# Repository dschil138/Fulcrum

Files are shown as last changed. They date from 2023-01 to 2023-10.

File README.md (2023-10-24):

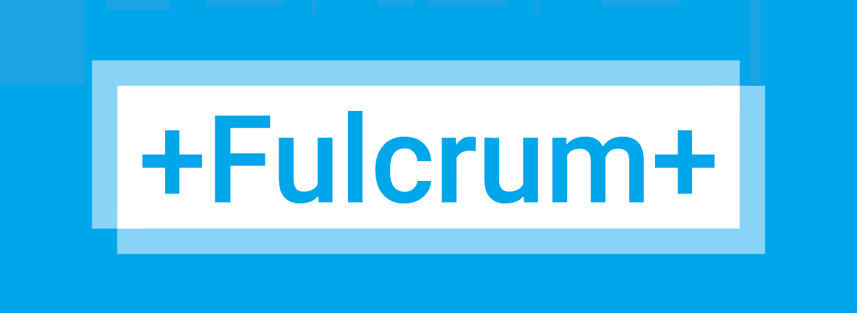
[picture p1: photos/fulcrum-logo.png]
Fulcrum Keyboard Logo


## <h2 align="center"> Leverage the power of opposable thumbs</h2>

<!-- # Fulcrum Keyboard -->

The Fulcrum is a wireless ergonomic keyboard that features 5-way switch joysticks, which are mounted horizontally to take advantage your thumb's natural range of motion.

It runs KMK circuitpython firmware on an nRF52840 microcontroller.

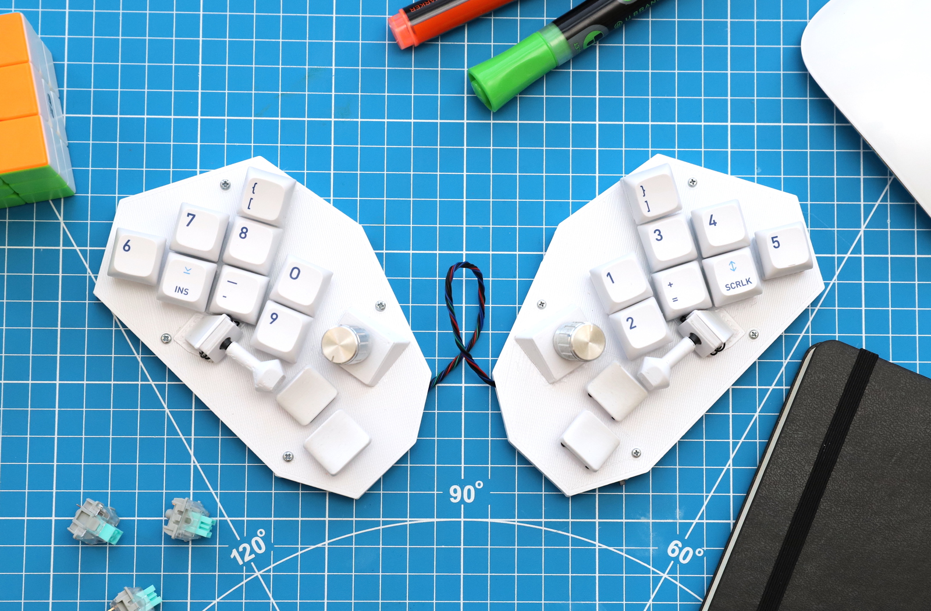
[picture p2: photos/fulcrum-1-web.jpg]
Photo of the Fulcrum Keyboard


There are currently two versions of the Fulcrum: the **20-key version** pictured here, and a **40-key version** pictured below. (These key counts do not include the 5-way switches.)

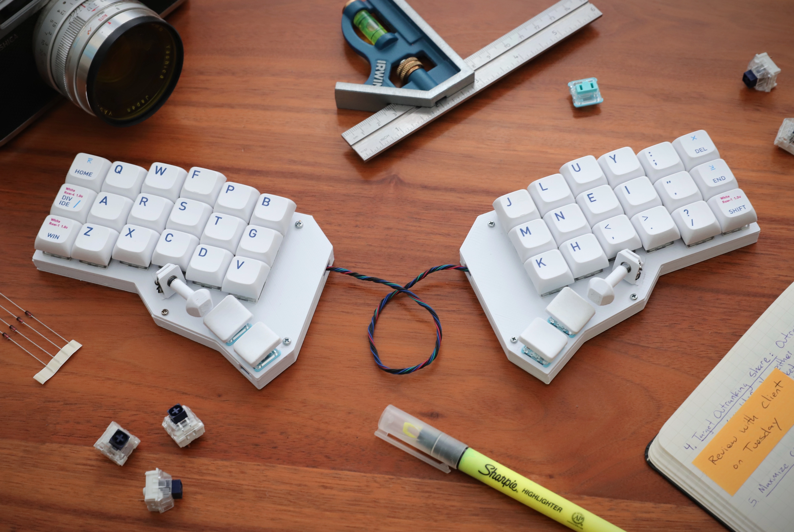
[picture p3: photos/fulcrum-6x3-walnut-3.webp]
40 key version


*(NOTE: there is now a 34-key "beta" version as well)*

## Fulcrum in the Media
- [HackerNews](https://news.ycombinator.com/item?id=34656652)
- [KBD.news (20 key)](https://kbd.news/Fulcrum-1862.html)
- [KBD.news (40 key)](https://kbd.news/40-Fulcrum-1879.html)
- [Hackaday.com](https://hackaday.com/2023/02/04/fulcrum-foils-finger-fatigue/)

# Keyboard Features

## 👍 5-Way Switch Thumb Joysticks

Our thumbs are criminally underutilized on regular keyboards. Your two most capable fingers, both relegated to just one key - the space bar.

Many ergonomic keyboards try to rectify this problem by giving each thumb several keys. This is an improvement, but most people quickly find that it is actually quite difficult for your thumb to stretch over multiple keys and hit something accurately, let alone comfortably. More inefficency!

So what's going on with our phones? Look at how well we use our thumbs to type there. On a smartphone, our thumbs are fast, accurate, and dexterous. Incredibly efficient. What's the disconnect? Why are they so nimble over there, and so lumbering and inaccurate on our keyboards?

> The disconnect is that our thumbs are *opposable*, but for some reason our keyboards keep insisting on giving them the same type of key as our other fingers. Our thumbs want to move in a different direction!

> The 5-way switch joysticks on the Fulcrum are mounted sideways, allowing you to use your thumbs in a dimension that is more similar to how they move when you type on a smartphone. This immediately feels comfortable and natural, because it is how you already use your thumbs most other parts of your daily life.

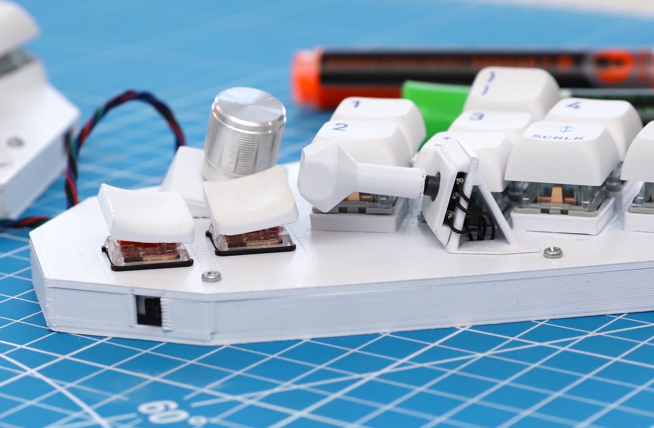
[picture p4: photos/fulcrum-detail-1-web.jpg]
Photo of the Fulcrum Keyboard


With the regular key switch placed below joystick, this actually puts six different actions at the tip of each thumb with very minimal movement.

Most importantly, all of these actions are easily paired with other key presses elsewhere on the keyboard.

> **Note**
> Useful tips to help you choose what functions to assign to the joysticks:
> 1. Pressing "down" (towards the desk) on the joystick should be a layer switch when held. This is because it is the easiest motion to hold & press other keys.
> 2. Mod-Tap works well on them, so consider a "hold" & "tap" key for each
> 3.  The first few times you use them, you may find it hard to not move the whole board around a bit when pressing certain directions. This will go away after a day or two of getting used to the movements.

## Thumb joystick on 20 key Fulcrum  Combos
A combo is when you press two or more keys at the same time to output a different key.

The 20-key version of this keyboard uses a significant number of combos. You don't have to keep them all, but some are important.

Here is a guide to most of the important combos. They are generally split into combos that output words, and combos that output keys or actions (like "delete").

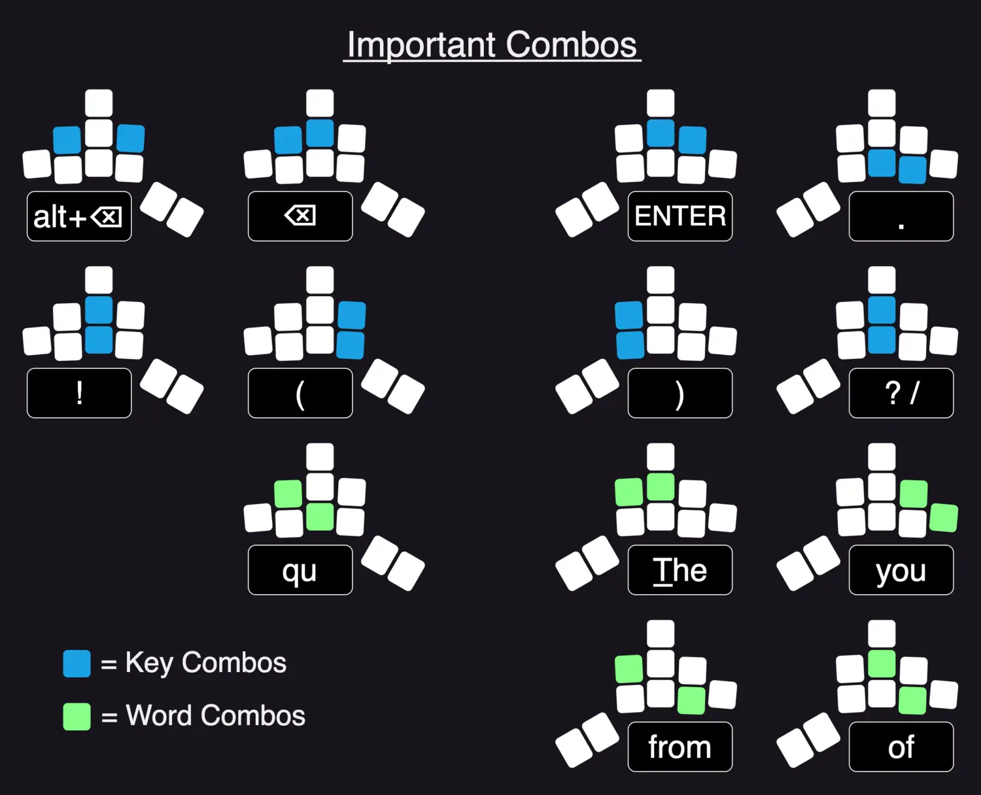
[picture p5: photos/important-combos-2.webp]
Important Combos Diagram


## Thumb joystick on 20 key Fulcrum Word Keys

We type the words "<ins>the</ins>" and "<ins>and</ins>" a lot. Even more-so if you include when they appear as a part of another word (<ins>the</ins>m, <ins>the</ins>y, ano<ins>the</ins>r).

So this keyboard just gives them their own keys!

It's funny, we never question giving Z or Q their own key, but the trigram "the" is more common than either of those letters (2-3 times as common!). Using a single key to type "the" just makes sense.

## 🪜 Optional Key Risers
Most keys have optional risers to help them conform to the shape of your hand. Every key gets them except the thumb keys and the bottom two middle finger keys. The top middle finger key gets a slanted riser.  

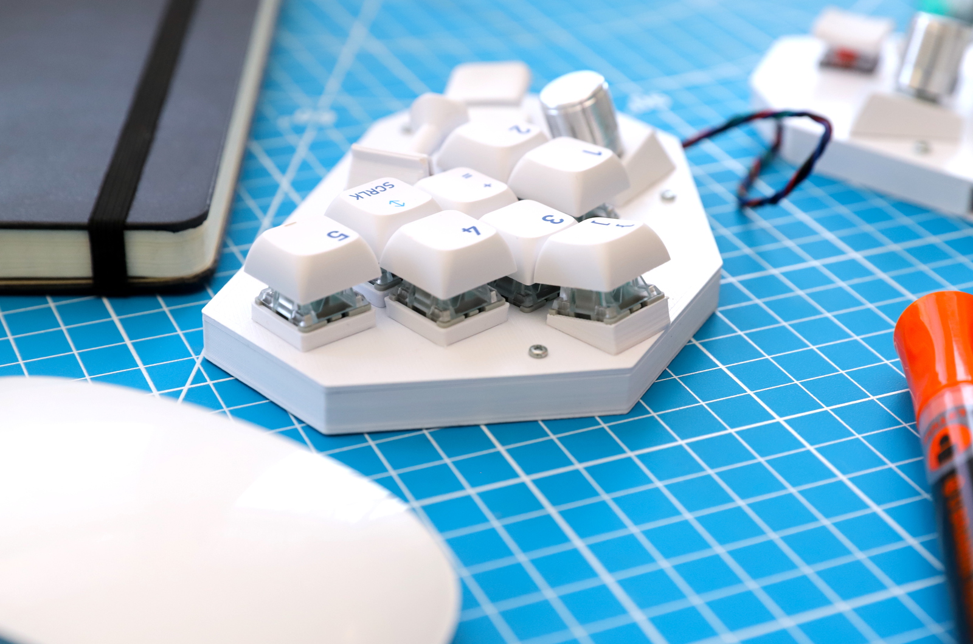
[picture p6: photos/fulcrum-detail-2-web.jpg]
Photo of the Fulcrum Keyboard Detail


To use them, print the top plate of the case as normal, and superglue the risers on top. The switches should friction fit into the risers.

>**Note** 
>The four thumb keys are low profile choc switches, as opposed to the rest which are MX. This is to accommodate the fact that your thumb sits on lower plane than the rest of your fingers, helping to further reduce hand strain.
>
>The custom angled keycaps for the thumb keys can be found in the STLs folder. They are a remix of the great [LPX](https://github.com/levpopov/LPX) design by levpopov.

## Thumb joystick on 20 key Fulcrum  Rotary Encoders

By default, the left rotary encoder scrubs through history (undo/redo) and the right side controls volume. Some other uses include tab switching, scrolling, and tool adjustment in apps like photoshop.

 Similarly to the key risers, the encoders use a slanted riser to tilt the encoders into a more ergonomic position.

# 🛠️ Build Guide

## Thumb joystick on 20 key Fulcrum  Version Files

There are currently two versions of the Fulcrum - the 20-key version you see in most of the photos above, and a 40-key version pictured below.

This repo contains the STLs and firmware files for both versions. The 40-key version is newer - the keymap layouts are not as well-developed. But it is fully functional!

*(NOTE: there is now a 34-key "beta" version as well)*

## Thumb joystick on 20 key Fulcrum  BOM

| Part | Quantity | Notes| 
| :--- | :---: | :--- |
| nRF52840 Microcontroller | 1 | Recommended: Adafruit nRF52340 [Itsy Bitsy](https://www.adafruit.com/product/4481) or [Feather](https://www.adafruit.com/product/4062) version.|
| Choc key switches | 4 | For thumb keys|
| MX key switches | 16 | (36 if making the 40% version) For non-thumb keys  |
| 1N4148 Diodes  | 22 | (42 for the 40% version) Only one is needed for each 5-way switch | 
| Rotary Encoders | 2 | Recommended: EC11, but you do you|
| 5-Way Switches | 2 | - [These](https://www.amazon.com/10x10x9mm-Momentary-Square-Tactile-Switch/dp/B00E6QM2F0/) are cheap and ubiquitous<br>- [SKRHACE010](https://www.aliexpress.us/item/3256804101921532.html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) are better (lower operateing force & rated for longer use) |
| On/Off switch | 1 | |SKRHACE010
| USB-C Breakout Board | 1 | (optional)|
| Lipo battery | 1 | At least 500 mAh, this thing chews batteries |
| [TP4056](https://www.aliexpress.us/item/2251832464987361.html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) Lipo Charger | 1 | Not needed if your microcontroller has built-in lipo charging, like the Feather nRF52840 |
| Wire |  | Recommend 30AWG or 28AWG|

## Thumb joystick on 20 key Fulcrum  Wiring 
While this is a split keyboard, I have chosen to hard-wire the halves together. You can follow my wiring if you'd like, or if you want to use a TRRS cable to connect the halves, KMK does offer I2C connection functionality.

Note that the top key is wired as if it were part of the thumb key row.
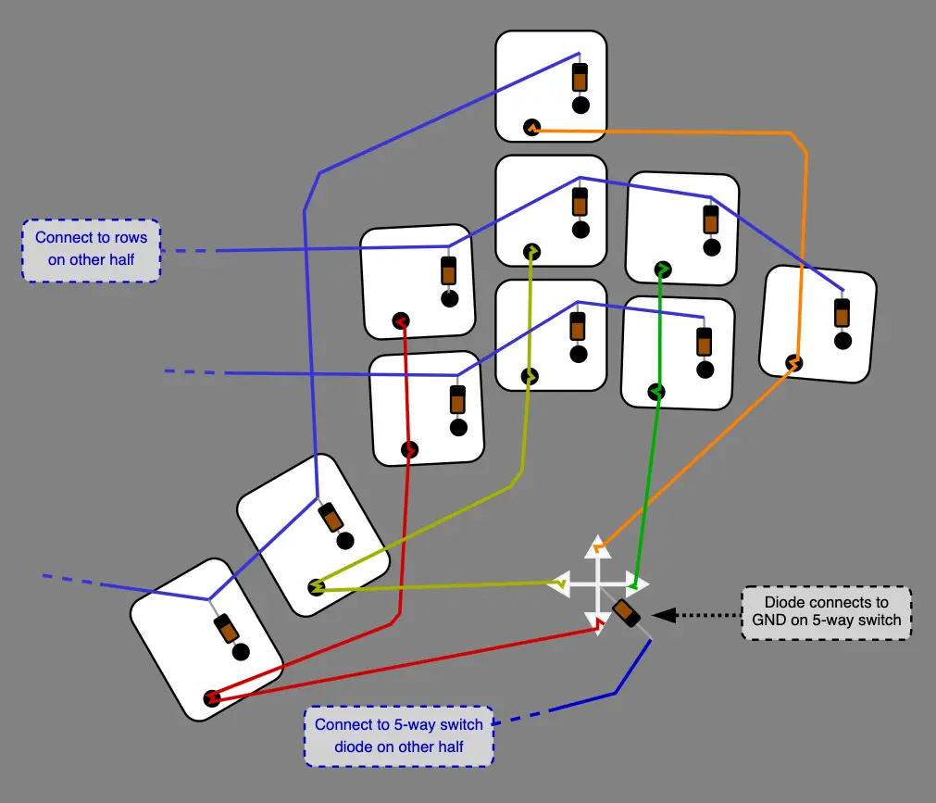
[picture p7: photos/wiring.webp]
Wiring Diagram


There is also a [full wiring diagram](https://user-images.githubusercontent.com/11950317/218586755-9777235f-c6fa-4484-ac11-7d081c10044d.jpg) which shows the microcontroller connections

## Thumb joystick on 20 key Fulcrum Placing The Joysticks

The 5-way switches are mounted using an angled platform. It consists of two pieces which clamp around the base of the switch. The whole assembly is then superglued to the top of the case.

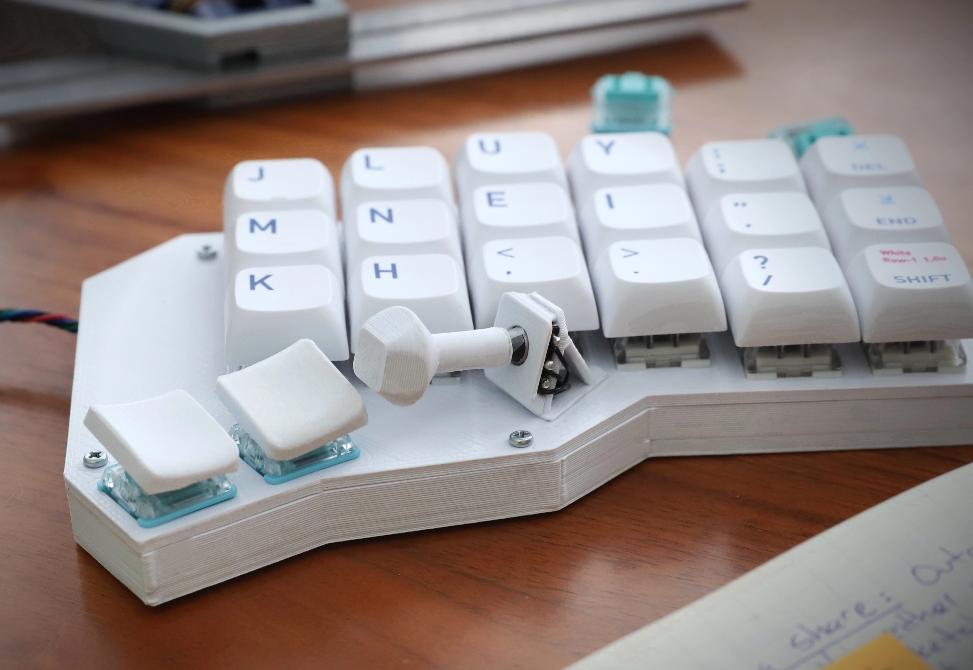
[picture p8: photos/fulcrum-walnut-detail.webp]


There is no precise place to glue this little platform. There is meant to be flexibility there so that you can mount it where it feels comfortable to you. You may want to consider lengthening or shortening the joystick as well, with a longer joystick providing extra leverage on the switch.

There is a small hole in the bottom of the platform piece. When you find the placement of the switch that you want, drill a small hole in the top of the main case to line up with that hole so you can feed the wires through. They connect into the rest of the matrix as if they were regular keys.

## 🔄 Hotswap Sockets
There is no PCB for this keyboard, it is a hand-wired build. But of course we all still want to be able to swap out different switches. So I've made printable hot-swap socket holders that allow you to do that. You can find the MX & Choc versions [here](https://www.printables.com/model/284057-hot-swap-socket-holders)

---
# Thumb joystick on 20 key Fulcrum Layer Keymaps
(blank spaces on joystick directions inherit the key from the previous layer)

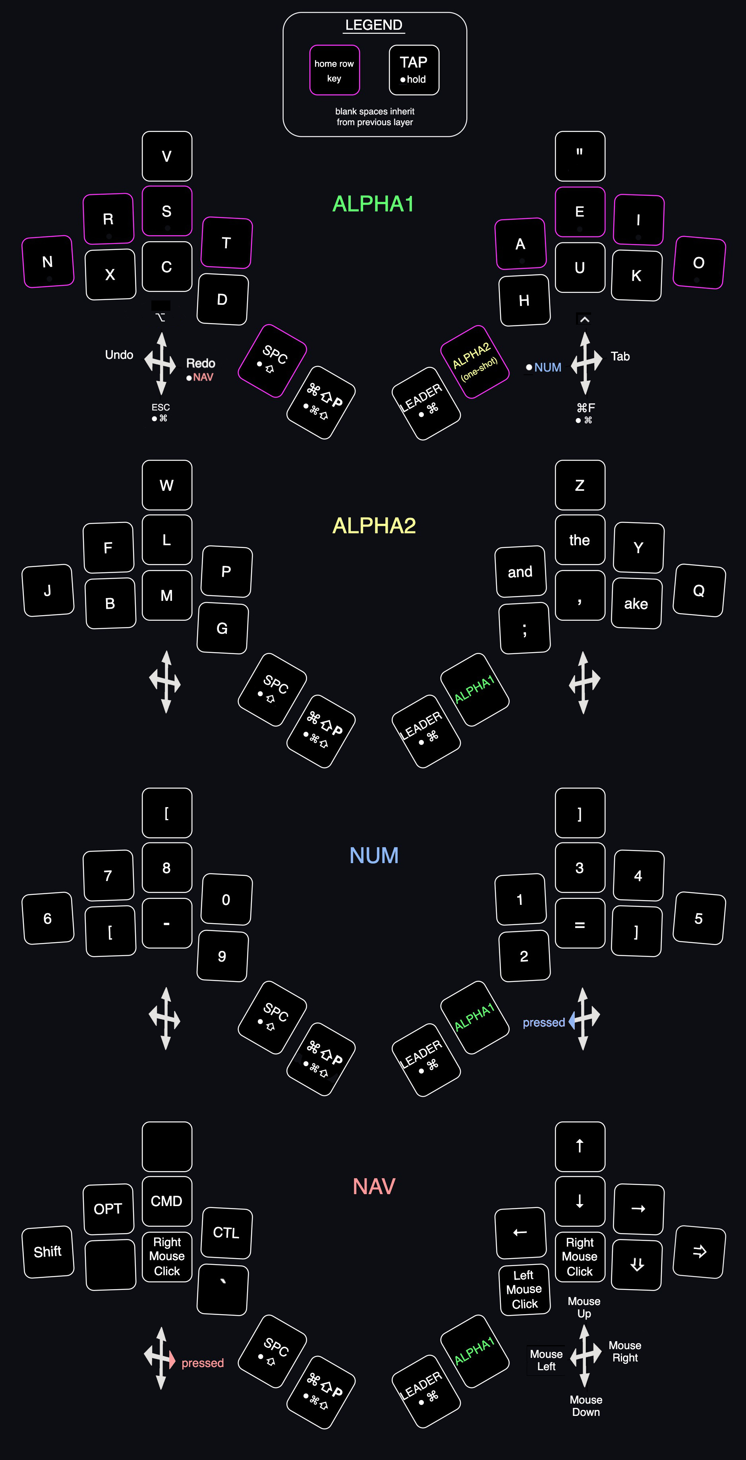
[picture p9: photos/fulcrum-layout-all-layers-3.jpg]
All Fulcrum Layers


## Credits

 - The innovative idea of reducing the overall number of keys by putting half of the letters on a second layer comes from [Ben Vallack](https://www.youtube.com/c/BenVallack)

 - The angled keycaps for the thumb keys are a remix of levpopov's great [LPX](https://github.com/levpopov/LPX) design

- The main design inspiration behind the shape of the 40-key Fulcrum is from the [Corne Keyboard](https://github.com/foostan/crkbd)

 - Many of the custom emojis used in this README are remixed files from flaticon [<a href="https://www.flaticon.com/free-icons/upload" title="upload icons">1</a>, <a href="https://www.flaticon.com/free-icons/placement" title="placement icons">2</a>, <a href="https://www.flaticon.com/free-icons/layers" title="layers icons">3</a>, <a href="https://www.flaticon.com/free-icons/ctrl" title="ctrl icons">4</a>, <a href="https://www.flaticon.com/free-icons/type" title="type icons">5</a>, <a href="https://www.flaticon.com/free-icons/checklist" title="checklist icons">6</a>, <a href="https://www.flaticon.com/free-icons/storage" title="storage icons">7</a>, <a href="https://www.flaticon.com/free-icons/knob" title="knob icons">8</a>, <a href="https://www.flaticon.com/free-icons/wire" title="wire icons">9</a>, <a href="https://www.flaticon.com/free-icons/levels" title="levels icons">10</a>]

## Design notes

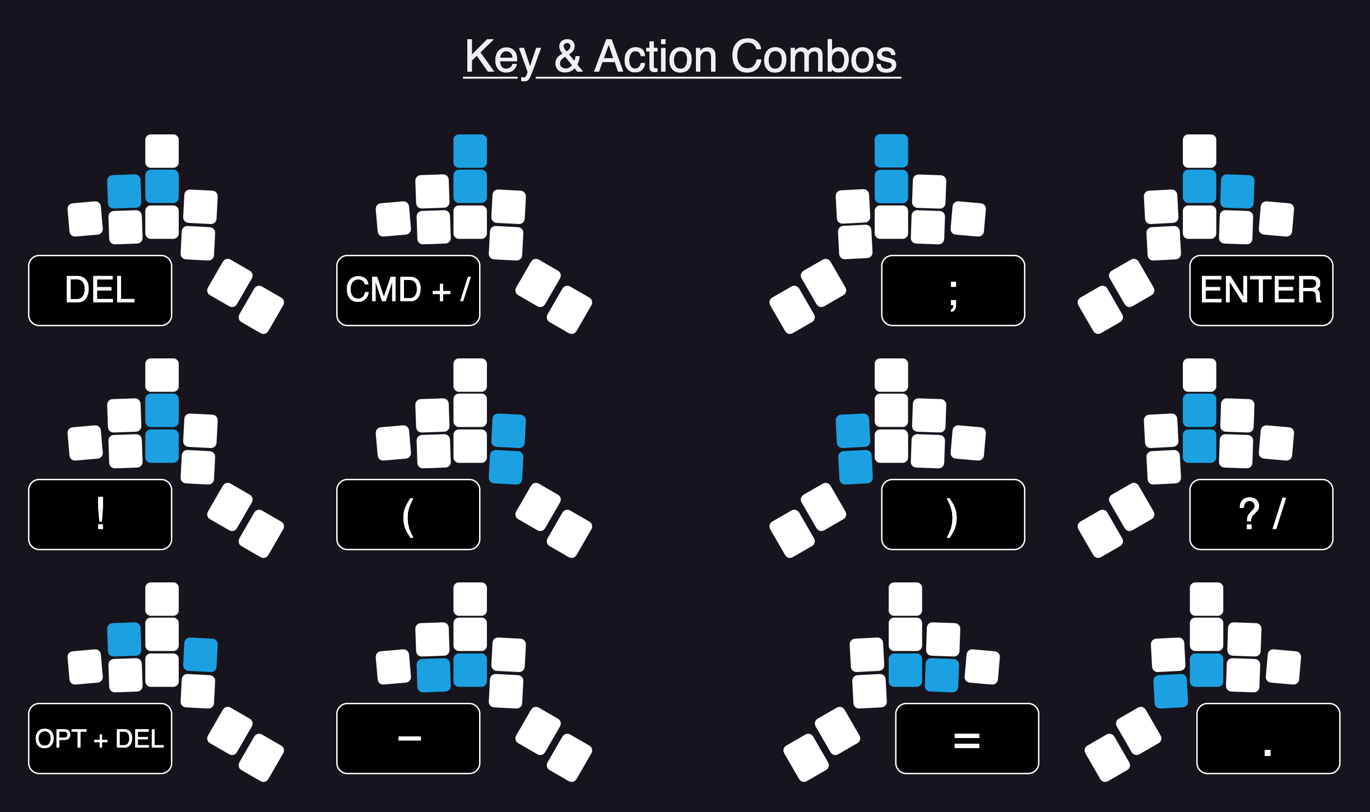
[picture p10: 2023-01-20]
photos/key-action-combos-2.png

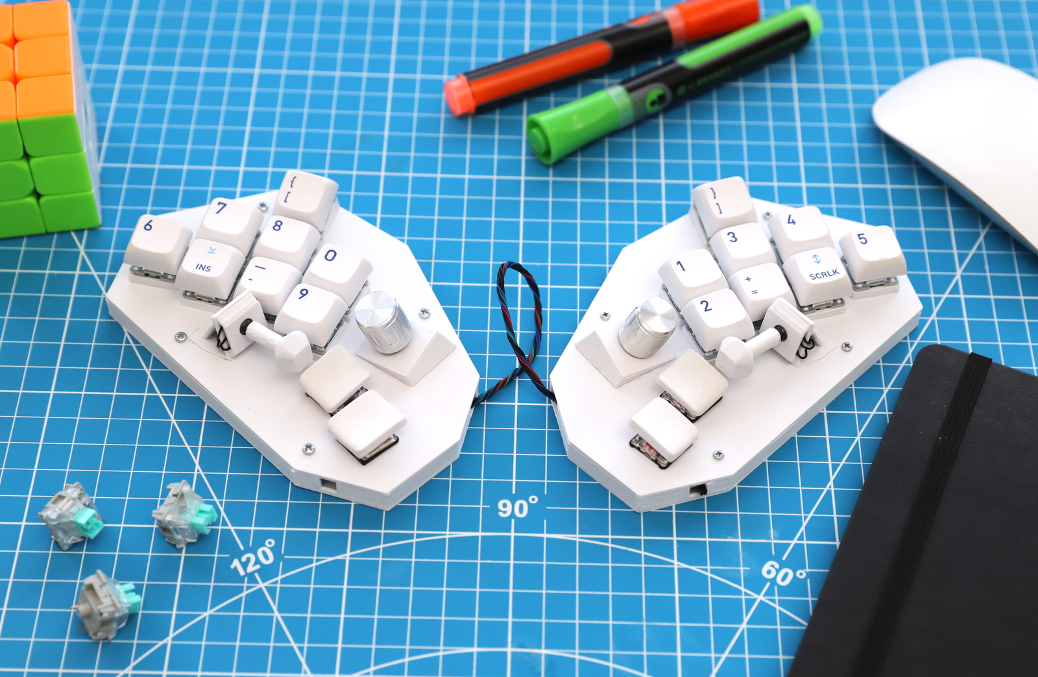
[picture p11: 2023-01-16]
photos/fulcrum-2-web.jpg

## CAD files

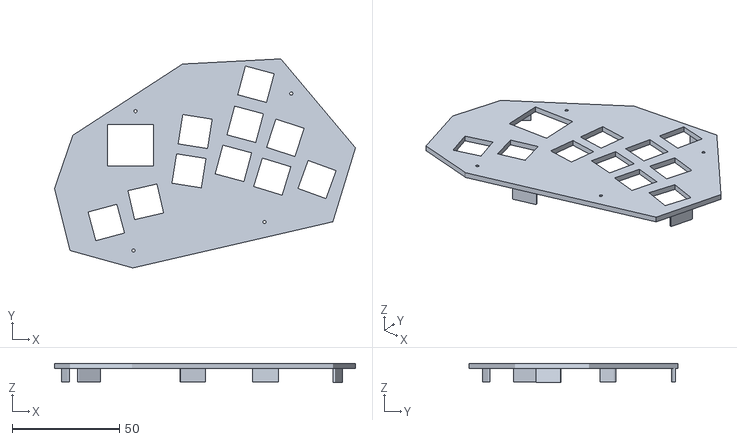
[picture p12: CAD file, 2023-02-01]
STLs/20-key/fulcrum-20-top-right.stl
140.6 x 97.7 x 9.00

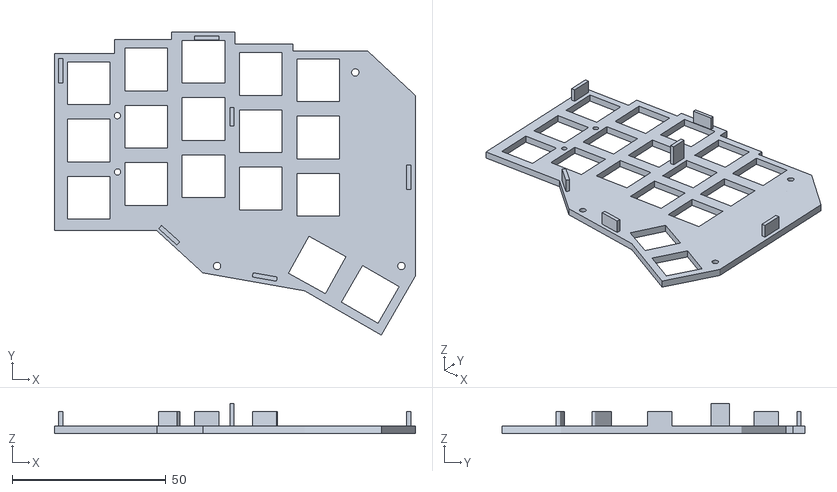
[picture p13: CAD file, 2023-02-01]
STLs/34-key-beta/5x3-fulcrum-top-right.stl
117.5 x 98.7 x 9.90

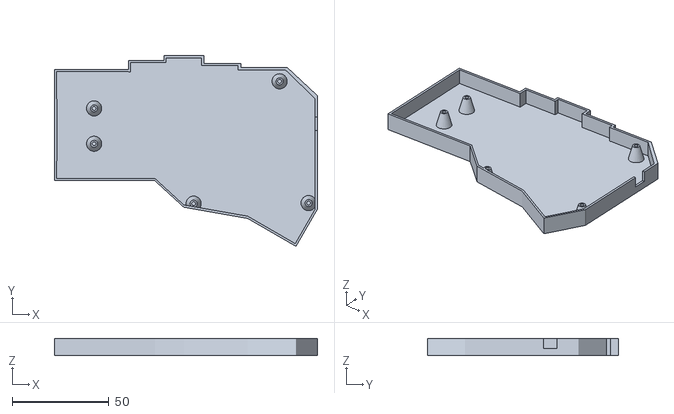
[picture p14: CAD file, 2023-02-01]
STLs/40-key/6x3-fulcrum-bottom-left.stl
136.1 x 98.7 x 9.00

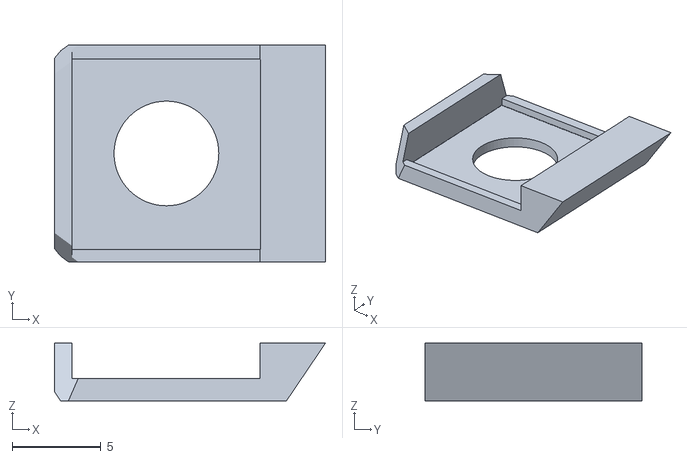
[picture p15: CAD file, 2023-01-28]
STLs/5-way top.stl
15.3 x 12.2 x 3.25

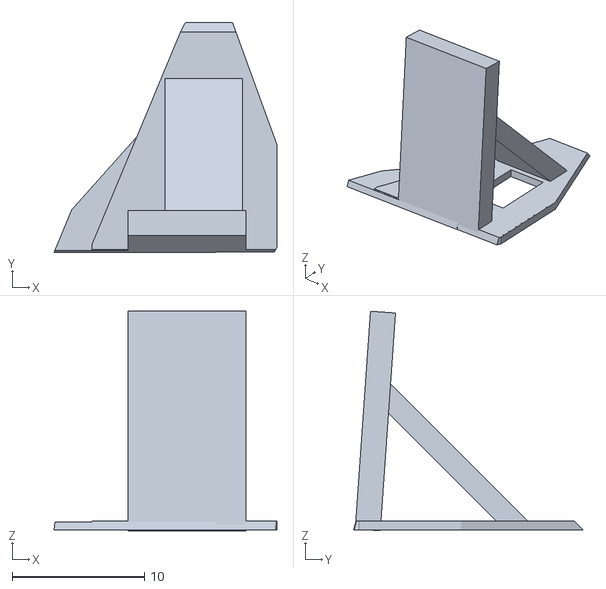
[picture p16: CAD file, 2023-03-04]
STLs/SKRH-models-beta/SKRH-platform.stl
16.9 x 17.4 x 16.6

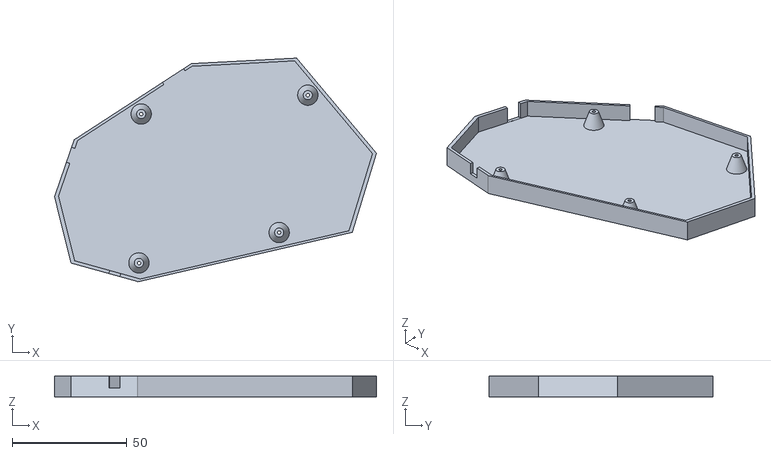
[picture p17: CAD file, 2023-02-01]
STLs/20-key/fulcrum-20-bottom-right.stl
140.6 x 97.7 x 9.00

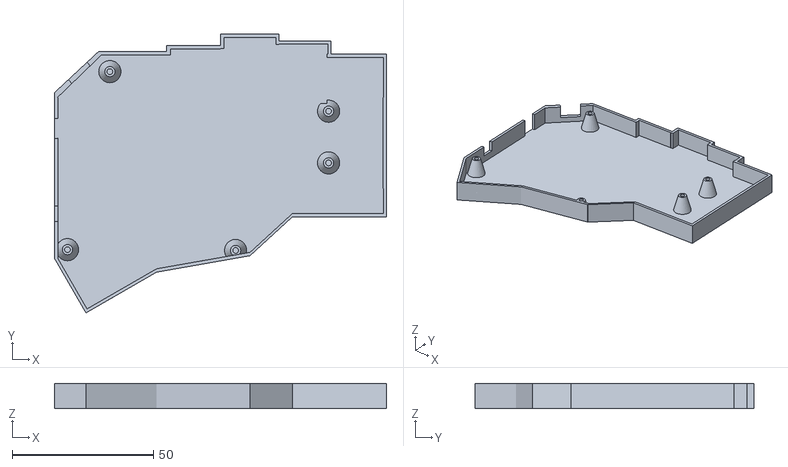
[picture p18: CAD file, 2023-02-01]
STLs/34-key-beta/5x3-fulcrum-bottom-right.stl
117.5 x 98.7 x 9.00

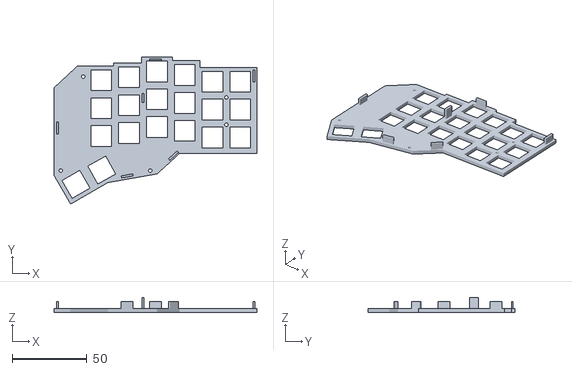
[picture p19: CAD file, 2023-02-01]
STLs/40-key/6x3-fulcrum-top-left.stl
136.1 x 98.7 x 9.90

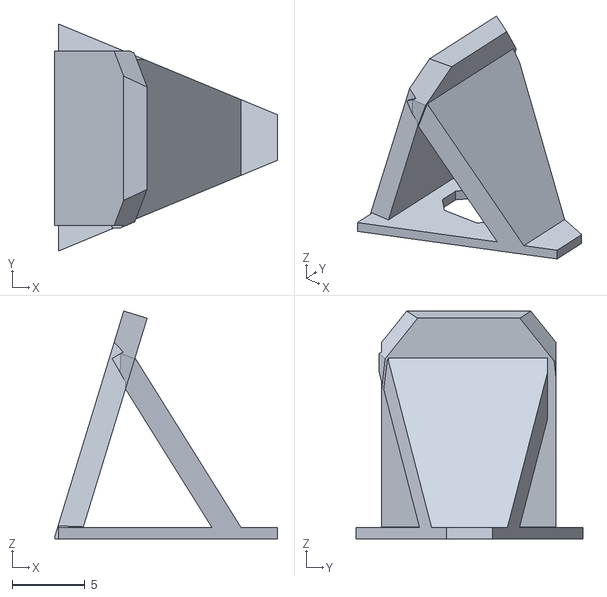
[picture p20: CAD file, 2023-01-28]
STLs/5-way-bottom.stl
15.4 x 15.7 x 15.7

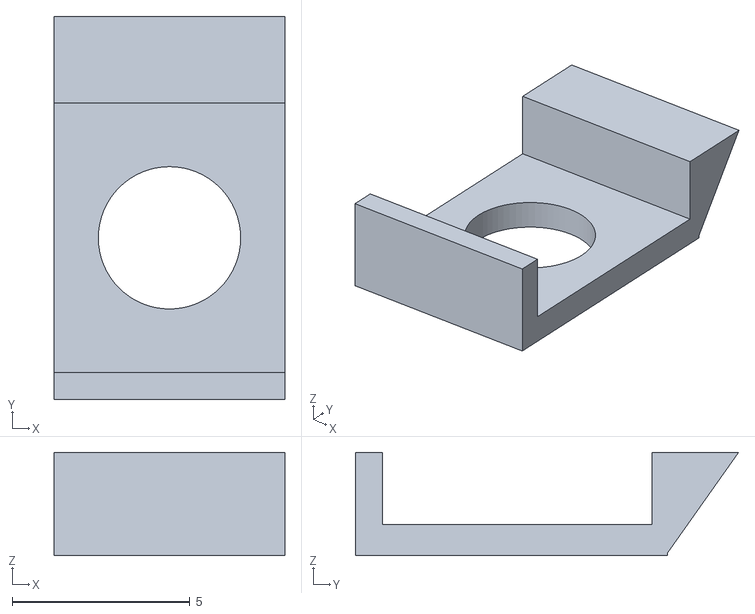
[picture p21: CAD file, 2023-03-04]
STLs/SKRH-models-beta/SKRH-cover.stl
6.50 x 10.8 x 2.90

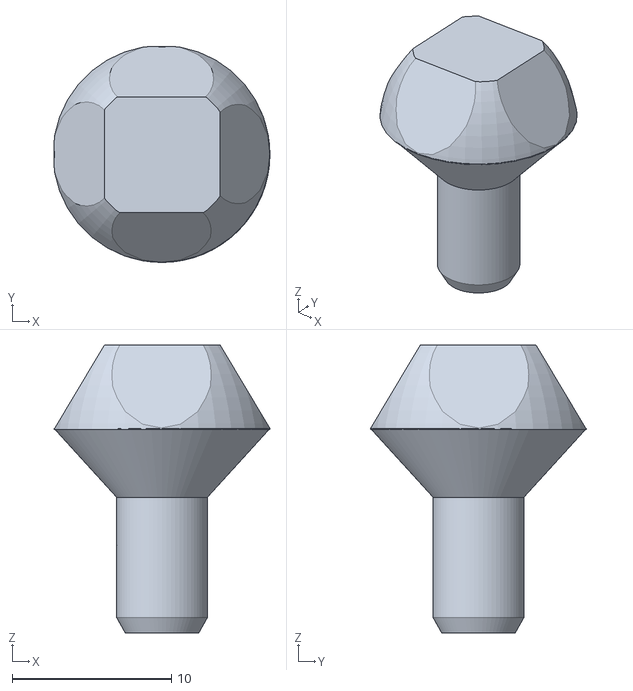
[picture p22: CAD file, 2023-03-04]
STLs/SKRH-models-beta/SKRH-joystick.stl
13.6 x 13.6 x 18.1

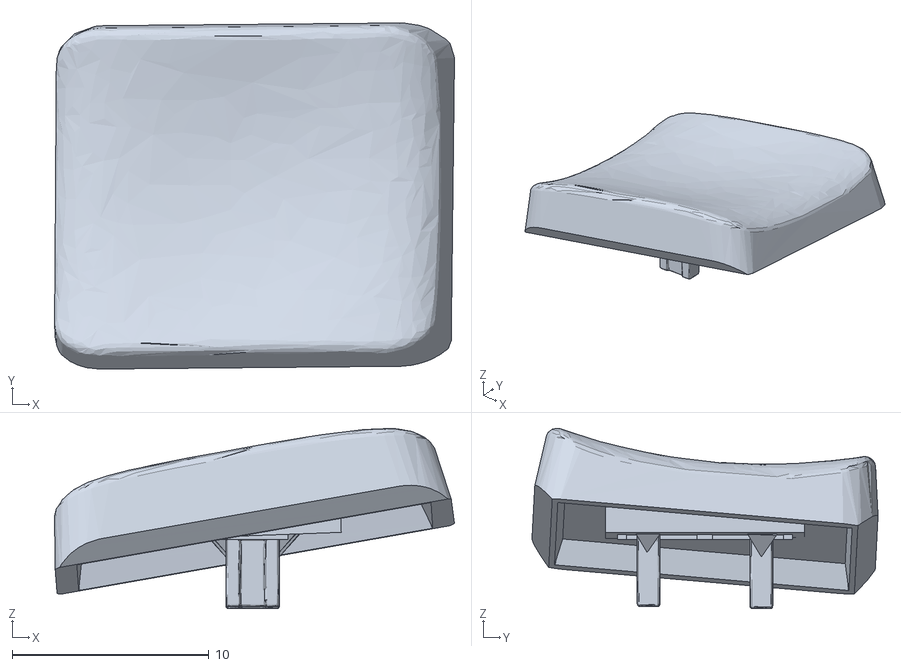
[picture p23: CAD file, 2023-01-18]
STLs/thumb-keycap-horizontal.stl
20.3 x 17.6 x 9.16

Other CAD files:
STLs/20-key/fulcrum-20-bottom-left.stl
STLs/34-key-beta/5x3-fulcrum-bottom-left.stl
STLs/40-key/6x3 Fulcrum-bottom-right.stl
STLs/20-key/fulcrum-20-top-left.stl
STLs/34-key-beta/5x3-fulcrum-top-left.stl
STLs/40-key/6x3-fulcrum-top-right.stl
STLs/joystick.stl
STLs/key-riser-slant.stl
STLs/key-riser.stl
STLs/rotary-cap.stl
STLs/thumb-keycap-vertical.stl

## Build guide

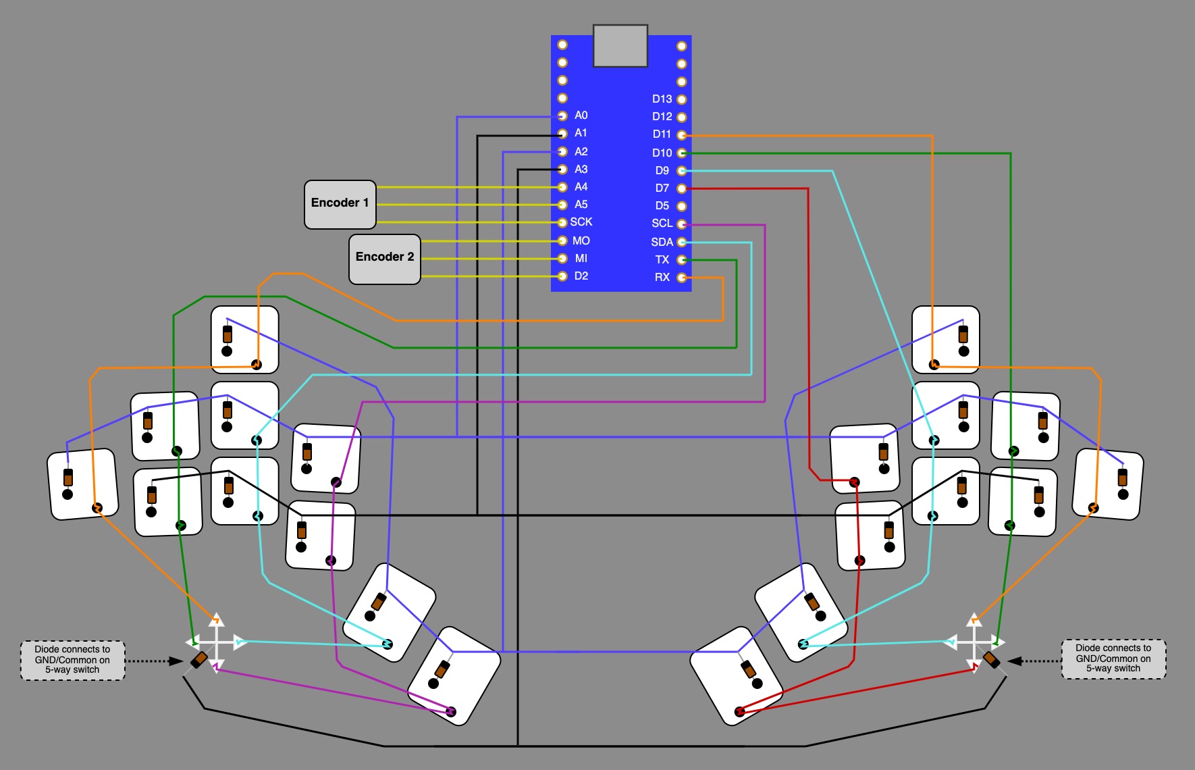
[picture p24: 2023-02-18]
photos/wiring-full.jpg

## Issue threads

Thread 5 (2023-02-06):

README typo (relegated vs regulated)

tannerntannern, 2023-02-06:
Cool project.  I love this sentence from the README, but I believe it has a typo:
> Your two most capable fingers, both **regulated** to just one key - the space bar.

I believe "regulated" should be ["relegated"](https://www.dictionary.com/browse/relegated)

dschil138, 2023-02-06:
ah, yep you're right. Good catch. Will fix in my next commit. I'll close this then so I don't forget. Thanks!

dschil138, 2023-02-09:
Fixed on last commit. thanks again

Closed 2023-02-09.

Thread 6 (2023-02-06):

no rotary encoder on the 40-key version?

asg0451, 2023-02-06:
...is there one on the 36-key version (and can you add some pics of it pls!)?

dschil138, 2023-02-06:
I didn’t include any rotary encoders on the 40-key bc I thought I wouldn’t have enough pins after the larger key matrix. However, I believe there is still enough to add one back if you’d like! You could just steal a few lines of code from the 20-key firmware files.

I don't have any pics of the 36 bc I’ve actually never built it. Someone requested the case files so I just made them really quick and uploaded them. They are making it now, so maybe they can provide some pics when they finish. It’s the same as the 40, just with the outside pinky columns cut off.

Speaking of which… that would make it 34 keys, not 36. I’ll have to change that.

But yeah, on the 34 key version, you might actually have enough pins to add back *both* rotary encoders if you wanted.

asg0451, 2023-02-06:
gotcha, thanks. maybe the 34 is the move then....

dschil138, 2023-02-09:
btw here are some pics of the 34-key build someone is working on right now.

If you do make one, please let me know what you think about the case design especially. This person didn't want to use a usb-c breakout board so they modified the case a bit to put the controller on top. If the angled corner is an issue for people I think I am going go remove it, just to make things easier.

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

asg0451, 2023-02-09:
nice, thanks! i will for sure

SyphinGames, 2023-06-16:
would you mind if I "attempted to design a pcb for us crazy people who want one?

dschil138, 2023-07-01:
a PCB would be amazing. I have actually been wishing I had one for awhile now, but idk how to make them. If you've got the skills, go for it!

nebula-it, 2024-12-06:
@SyphinGames in case you do, I'd suggest using roller encoders instead of rotary, they are far more ergonomic to operate

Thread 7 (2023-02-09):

Detailed wiring

Gerben1701, 2023-02-09:
Hello dschil138,
I'm interested in building this, your opposable thumb control seems unique and definitely stands out!
I'm not much of a programmer (yet), but I know my way around CAD and a 3D printer; first step for me is building the 20-key version as-is and go from there, probably some remodelling then.
The wiring however seems incomplete or is it something standard I just don't know? Can you provide details or a reference?
Thanks for the share!

dschil138, 2023-02-09:
Sure, I can definitely help you out there. Could you lmk how much background info you know on keyboard wiring already? Specifically if you are familiar with key matrix wiring? Don’t wanna give you a bunch of info you already know.

The current diagram is definitely incomplete. For the most part, the other side is just mirrored, and the rows are connected as if the whole thing is just one big keyboard (and not split). So it has 8 columns and 4 rows (including the 5-way switches)

The main purpose for the diagram was to illustrate how the top key is wired into the same row as the thumb keys, and to show how the 5-way switches are integrated. It does assume the user is familiar with key matrix wiring tho.

I can give you more info on that if you want, just want to understand which parts you are looking for clarification on

Gerben1701, 2023-02-10:
That'd be great! This will be my first keyboard build and also my first arduino build. My background is in mechanical engineering, some electrical engineering and the occasional programming of PLCs, for fun I developed and build some analog guitar effects. As to keyboards, I only know the one basic: it's rows and columns... but I'm reading up on it.
For your build: Basically, how to wire up, connect which leads to which inputs? I think I should be able to figure it out from the code, but I really don't want to mess up :)

dschil138, 2023-02-13:
Hey so I am still fine-tuning this, and will post a final version to the repo eventually, but here is a more complete guide for you.

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

This is showing how the rows and columns would be wired to the GPIO pins currently spelled out in the 20-key version files in this repo, but you can really wire them to whatever inputs you want. Just change them accordingly in the kb.py file. You don't have to do exactly what I did here.

As for more general keyboard wiring questions, QMK has a pretty good handwiring guide [here ](https://docs.qmk.fm/#/hand_wire)which should help. There also some good videos on youtube if you look around there.

Gerben1701, 2023-02-15:
Thanks very much!
That makes the instructions complete. 🙂
(Parts are ordered, ETA ranging from a few days to ~3 weeks. In the meantime printing and maybe iterating 3D parts.)

Closed 2023-02-15.

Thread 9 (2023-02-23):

Wiring Diagram for the 40 key version

angel12, 2023-02-23:
Do you have a wiring diagram (or even just a picture of the underside of the switches) for the 40 key version?

I'm about to start printing the case, and should be getting my microcontrollers within the next week or so, so I'll be ready to start wiring my board together here soon

dschil138, 2023-02-27:
Hey so I don't have a diagram or anything for the 40 key version, as it's just a standard key matrix on that one. The reason i  made one for the 20-key version was that the rows are wired kind of oddly. But any standard key matrix handwiring explainer should do you fine when it come to the 40-key version. I did whip this drawing up for you real quick tho. Hope it helps!
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

angel12, 2023-02-27:
That gets me started. I've done a few handwires, just never one with a 5 way switch

dschil138, 2023-02-28:
Actually I just realized that drawing is little misleading when it comes to the 5-way switch. The row wire won't connect around to each connection like that. There is a "common" pin on the 5-way switch, and you only have to connect the wire to that one pin. The 20-key version diagram shows that part really well tho

Please let me know how your build goes! I'd love to see pics when you get there

Closed 2023-06-16.

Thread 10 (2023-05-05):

What type of plastic is recommended for printing the parts?

Tobio89, 2023-05-05:
Hi, wondering what plastic type you've used for printing the parts.
Do you use the same plastic for the angled keycaps too?

dschil138, 2023-05-17:
I printed all mine in PLA+, including the keycaps. The case you could probably print in pretty much anything you want. The keycaps tho you are gonna have to do in something that prints well and you have a lot of control/experience with, because they are definitely a lot more difficult.

Closed 2023-06-16.

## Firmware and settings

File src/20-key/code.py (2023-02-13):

print("Starting")

import board
from kb import KMKKeyboard
from kmk.keys import KC
from kmk.modules.encoder import EncoderHandler
from kmk.modules.layers import Layers
from kmk.handlers.sequences import simple_key_sequence, send_string
from kmk.modules.combos import Combos, Chord, Sequence
from kmk.modules.tapdance import TapDance
from kmk.modules.oneshot import OneShot
from kmk.modules.modtap import ModTap
from kmk.hid import HIDModes
from kmk.extensions.media_keys import MediaKeys
from kmk.modules.mouse_keys import MouseKeys


# --------------- Module Settings -------------- 

combos = Combos()
encoder_handler = EncoderHandler()
encoder_handler_2 = EncoderHandler()

keyboard = KMKKeyboard()
keyboard.modules.append(combos)
keyboard.modules.append(TapDance())
keyboard.modules.append(Layers())
keyboard.modules.append(OneShot())
keyboard.modules.append(ModTap())
keyboard.modules.append(MouseKeys())
keyboard.extensions.append(MediaKeys())
keyboard.modules.append(encoder_handler)
keyboard.modules.append(encoder_handler_2)

encoder_handler.pins = ((board.SCK, board.A4, board.A5, False,),)
encoder_handler_2.pins = ((board.D2, board.MISO, board.MOSI, False,),)


# --------------- Macros ------------- 

redoMacro = simple_key_sequence((KC.LSFT(KC.LGUI(KC.Z),),))
t_h_e = send_string('the')
a_n_d = send_string('and')
a_k_e = send_string('ake')


# --------------- Combos --------------   

combos.combos = (

    # # #
    # # #---------- KEYS ----------

    # -- Left Hand --
    Chord((KC.R, KC.S), KC.BSPC, timeout=40),
    Chord((KC.T, KC.R), KC.LALT(KC.BSPC), timeout=10),
    Chord((KC.D, KC.C), KC.OS(KC.MO(1))),
    Chord((KC.S, KC.V), KC.LGUI(KC.SLASH)), 
    Chord((KC.T, KC.D), KC.LPRN),

    Chord((KC.N, KC.V), KC.TAB),
    Chord((KC.X, KC.C), KC.EQL),
    Chord((KC.S, KC.C), KC.EXLM),
    Chord((KC.R, KC.V), KC.LGUI(KC.F)),


    # -- Right Hand --
    Chord((KC.E, KC.I), KC.ENT),
    Chord((KC.H, KC.U), KC.DOT),
    Chord((KC.A, KC.K), KC.RPRN),
    Chord((KC.K, KC.H), KC.MINUS),
    Chord((KC.E, KC.H), KC.SLASH),
    
    Chord((KC.N1, KC.N3), KC.N2),
    Chord((KC.N3, KC.N4), KC.N5),
    Chord((KC.N6, KC.N8), KC.N7),
    Chord((KC.LEFT, KC.DOWN), KC.LGUI(KC.LEFT)),




    # # #
    # # #---------- WORDS ----------

    # -- Left Hand --
    Chord((KC.R, KC.N), send_string('rn'), timeout=50),
    Chord((KC.R, KC.C), send_string('qu')),


    # -- Right Hand --
    Chord((KC.I, KC.O), send_string('you')),
    Chord((KC.E, KC.U), send_string('of')),
    Chord((KC.A, KC.I), send_string('ay')),
    Chord((KC.A, KC.E), send_string('The')),

    Chord((KC.I, KC.H), send_string('ould')),
    Chord((KC.I, KC.K), send_string('ough')),
    Chord((KC.A, KC.U), send_string('from')),
    Chord((KC.K, KC.U), send_string('just')),


    # -- Both Hands --
    Chord((KC.R, KC.I, KC.O), send_string("you're "), timeout=80),
    Chord((KC.T, KC.I, KC.O), send_string('You'), timeout=80),
    Chord((KC.R, KC.C, KC.I), send_string('qu')),




    # # #
    # # # ---------- LEADER KEYS ---------- 

    # select to entire line
    Sequence((KC.LEADER, KC.I), simple_key_sequence((KC.LGUI(KC.LEFT),KC.LSFT(KC.LGUI(KC.RIGHT),),)), timeout=600),
    # Open iTerm
    Sequence((KC.LEADER, KC.T), simple_key_sequence((KC.LALT, KC.LALT)), timeout=600),

    # WINDOW LEFT 
    Sequence((KC.LEADER, KC.S), KC.LCTL(KC.LSFT(KC.LEFT),), timeout=600),
    # WINDOW RIGHT
    Sequence((KC.LEADER, KC.E), KC.LCTL(KC.LSFT(KC.RIGHT),), timeout=600),

    # CAPS LOCK
    Sequence((KC.LEADER, KC.C), KC.CAPS, timeout=600),
)



keyboard.keymap = (
    #
    # [0] ALPHA1
    #
    # (This first layer is difficult to read. Due to memory limitations, I've used as few variable
    # definitons as possible, instead defining the functionality of keys directly in the keymap here)
    [
                                                        KC.N,   KC.R,   KC.S,  KC.T,         KC.A,   KC.E,   KC.I,   KC.O,\
                                                        KC.NO,  KC.X,  KC.C,   KC.D,         KC.H,   KC.U,   KC.K,   KC.NO,\
        KC.V,      KC.NO,  KC.MT(KC.SPC, KC.LSFT, tap_time=80),   KC.MT(KC.ESC, KC.LSFT(KC.LGUI), tap_time=80),         KC.MT(KC.LGUI(KC.F), KC.RGUI, tap_time=80), KC.OS(KC.MO(1)), KC.NO,     KC.QUOTE,  \
            KC.MT(KC.OS(KC.MO(1)), KC.LALT),   KC.LT(4, KC.LGUI(KC.Z), tap_time=180),   KC.MO(3),   KC.LGUI,         KC.LEADER,   KC.MO(2),   KC.LT(4, KC.TAB, tap_time=180),   KC.RCTL,\
        # --- DEFAULT LAYER GUIDE FOR LAYOUT ---
        #
        #       N,   R,    S,     T,       -       A,      E,      I,      O,  
        #   V,       X,    C,     D,       -       K,      H,      U,         QUOTE, # <-- due to wiring, this is the top right middle finger key. V is the top left
        #     SPC/Shift,   ESC/CMD+SHIFT,  -     CMD+F/CMD,    ALPHA2, 
        #                                  -
        #                undo              -             Tab
        #            CMD      ALT          -        CTL      LEADER    
        #                NAV               -             NUM
    ],
    #
    # [1] ALPHA2 
    [
                    KC.J,    KC.F,    KC.L,    KC.P,          a_n_d,     t_h_e,     KC.Y,      KC.Q,\
                    KC.NO,   KC.B,    KC.M,    KC.G,          KC.SCLN,    KC.COMMA,    a_k_e,      KC.NO,\
        KC.W,         KC.TRNS,   KC.TRNS,  KC.TRNS,        KC.TRNS,   KC.TO(0),   KC.TRNS,            KC.Z, # <--this is the top right middle finger key. W is the top left
        KC.TRNS,   redoMacro,   redoMacro,   KC.TRNS,         KC.TRNS,   KC.TRNS,   KC.TRNS,  KC.TRNS,\
    ],
    # 
    # [2] NUM
    [
                        KC.NO,   KC.N6,     KC.N8,      KC.N0,         KC.N1,   KC.N3,   KC.N4,   KC.N5,\
                        KC.NO,   KC.LBRC,   KC.MINUS,   KC.N9,         KC.N2,   KC.EQL,  KC.RBRC, KC.NO,\
            KC.LBRC,             KC.NO,     KC.TRNS,    KC.TRNS,       KC.RGUI, KC.TRNS, KC.NO,               KC.RBRC,  \
        KC.TRNS,   redoMacro,   redoMacro,   KC.LSFT(KC.LGUI),         KC.TRNS,   KC.TRNS,   KC.TRNS,   KC.TRNS,\
    ],
    #
    # [3] NAV
    [
            KC.LSFT,   KC.LALT,   KC.LGUI,    KC.LCTL,             KC.LEFT,    KC.DOWN,   KC.RIGHT,   KC.RGUI(KC.RIGHT),\
            KC.NO,     KC.NO,     KC.MB_RMB,  KC.GRAVE,            KC.MB_LMB,  KC.MB_RMB, KC.NO,      KC.NO,\
        KC.UP,         KC.NO,     KC.TRNS,    KC.TRNS,             KC.RGUI,    KC.TRNS,   KC.NO,                KC.UP,  \
            KC.TRNS,   KC.TRNS,   KC.TRNS,    KC.TRNS,             KC.MS_DN,   KC.MS_LT,  KC.MS_RT,   KC.MS_UP,\
    ],
    #
    # [4] FUNCTION LAYER
    # (Define extra functionality here)
    [
                        KC.NO,   KC.NO,   KC.NO,   KC.NO,           KC.NO, KC.NO, KC.NO,  KC.NO,\
                        KC.NO,   KC.NO,   KC.NO,   KC.NO,           KC.NO, KC.NO, KC.NO,  KC.NO,\
            KC.NO,               KC.NO,   KC.NO,   KC.NO,           KC.NO, KC.NO, KC.NO,            KC.NO,\
                KC.RALT, redoMacro, KC.NO,  KC.LSFT(KC.LGUI),       KC.TRNS, KC.TRNS, KC.TRNS, KC.TRNS,\
    ],
)

#  Right Knob:             1 - volume,                      2 - TRNS,                       3- TRNS,                          4 - Mouse Scroll
encoder_handler.map = [((KC.VOLD, KC.VOLU, KC.MPLY,),), ((KC.TRNS, KC.TRNS, KC.TRNS,),), ((KC.TRNS, KC.TRNS, KC.TRNS,),),  ((KC.MW_UP, KC.MW_DN, KC.NO,),),]
encoder_handler_2.map = [((KC.LGUI(KC.Z), redoMacro, KC.NO,),), ((KC.TRNS, KC.TRNS, KC.TRNS,),), ((KC.LSFT(KC.LGUI(KC.LEFT)), KC.LSFT(KC.LGUI(KC.RIGHT)), KC.MPLY,),), ((KC.MW_DN, KC.MW_UP, KC.NO,),),]
#  Left Knob:              1 - Undo/Redo,                          2 - TRNS,                         3- Tab Left/Right,                                                     4 - Mouse Scroll


if __name__ == '__main__':
    keyboard.go(hid_type=HIDModes.BLE, ble_name='fulcrum')

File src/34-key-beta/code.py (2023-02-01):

print("Starting")

import board
from kb import KMKKeyboard
from kmk.keys import KC
from kmk.modules.layers import Layers
from kmk.handlers.sequences import simple_key_sequence, send_string
from kmk.modules.combos import Combos, Chord, Sequence
from kmk.modules.tapdance import TapDance
from kmk.modules.oneshot import OneShot
from kmk.modules.modtap import ModTap
from kmk.hid import HIDModes
from kmk.extensions.media_keys import MediaKeys
from kmk.modules.mouse_keys import MouseKeys


# --------------- Module Settings -------------- 

combos = Combos()

keyboard = KMKKeyboard()
keyboard.modules.append(combos)
keyboard.modules.append(TapDance())
keyboard.modules.append(Layers())
keyboard.modules.append(OneShot())
keyboard.modules.append(ModTap())
keyboard.modules.append(MouseKeys())
keyboard.extensions.append(MediaKeys())



# --------------- Macros ------------- 

redo = simple_key_sequence((KC.LSFT(KC.LGUI(KC.Z),),))
undo = simple_key_sequence((KC.LSFT(KC.LGUI(KC.Z),),))
SPC_sft = KC.MT(KC.LSFT, KC.SPC, timeout=80)
ESC_gui_sft = KC.MT(KC.LGUI(KC.LSFT), KC.ESC, timeout=80)
FIND_gui = KC.MT(KC.LGUI(KC.LSFT), KC.ESC, timeout=80)




# --------------- Combos --------------   

combos.combos = (

    # # #
    # # #---------- KEYS ----------

    # -- Left Hand --
    Chord((KC.R, KC.S), KC.BSPC, timeout=40),
    Chord((KC.T, KC.R), KC.LALT(KC.BSPC), timeout=10),
    Chord((KC.D, KC.C), KC.OS(KC.MO(1))),
    Chord((KC.T, KC.D), KC.LPRN),

    Chord((KC.S, KC.C), KC.EXLM),


    # -- Right Hand --
    Chord((KC.E, KC.I), KC.ENT),
    Chord((KC.N, KC.H), KC.RPRN),





    # # #
    # # # ---------- LEADER KEYS ---------- 

    # select to entire line
    Sequence((KC.LEADER, KC.I), simple_key_sequence((KC.LGUI(KC.LEFT),KC.LSFT(KC.LGUI(KC.RIGHT),),)), timeout=600),

    # WINDOW LEFT 
    Sequence((KC.LEADER, KC.S), KC.LCTL(KC.LSFT(KC.LEFT),), timeout=600),
    # WINDOW RIGHT
    Sequence((KC.LEADER, KC.E), KC.LCTL(KC.LSFT(KC.RIGHT),), timeout=600),

    # CAPS LOCK
    Sequence((KC.LEADER, KC.C), KC.CAPS, timeout=600),
)



keyboard.keymap = (

    #
    # [1] ALPHA2 
    [
                        KC.Q,  KC.W,  KC.F,  KC.P,  KC.B,                KC.J,  KC.L,  KC.U,  KC.Y,  KC.BSPC,\
                        KC.A,  KC.R,  KC.S,  KC.T,  KC.Q,                KC.M,  KC.N,  KC.E,  KC.I,  KC.O,\
                        KC.Z,  KC.X,  KC.C,  KC.D,  KC.V,                KC.K,  KC.H,  KC.COMMA, KC.DOT, KC.SLASH,\
        KC.NO, KC.NO, KC.NO, KC.NO,      SPC_sft,  ESC_gui_sft,        FIND_gui,  KC.MO(1),       KC.NO,  KC.NO,  KC.NO,  KC.NO   
        KC.NO,  KC.NO,      KC.LALT,  undo,  KC.LGUI,  redo,           KC.MO(2),  KC.LEADER,  KC.TAB,  KC.RCTL,       KC.NO, KC.NO\
    #                       forward,   up,     back,    down             down,      back,      up,     forward

    ],
    # 
    # [2] NUM
    [
            KC.NO, KC.NO,     KC.UP,     KC.NO,     KC.NO,           KC.NO, KC.N7,  KC.N8,   KC.N9,   KC.N0, \
            KC.NO, KC.RIGHT,  KC.DOWN,   KC.LEFT,   KC.NO,           KC.NO, KC.N4,  KC.N5,   KC.N6,   KC.N7, \
            KC.NO, KC.NO,     KC.NO,     KC.NO,     KC.NO,           KC.NO, KC.N1,  KC.N2,   KC.N3,   KC.NO, \
           KC.TRNS,   KC.TRNS,   KC.TRNS, KC.TRNS, KC.TRNS,         KC.TRNS, KC.TRNS,   KC.TRNS,   KC.TRNS,    KC.TRNS,\
           KC.TRNS,   KC.TRNS,   KC.TRNS, KC.TRNS, KC.TRNS,         KC.TRNS, KC.TRNS,   KC.TRNS,   KC.TRNS,    KC.TRNS,\
    ],
    # 
    # [2] MACRO LAYER - define your own actions
    [
                     KC.NO,  KC.NO,   KC.NO,   KC.NO, KC.NO,           KC.NO, KC.NO,  KC.NO,   KC.NO,   KC.NO,  \
                     KC.NO,  KC.NO,   KC.NO,   KC.NO, KC.NO,           KC.NO, KC.NO,  KC.NO,   KC.NO,   KC.NO,  \
                     KC.NO,  KC.NO,   KC.NO,   KC.NO, KC.NO,           KC.NO, KC.NO,  KC.NO,   KC.NO,   KC.NO,  \
             KC.TRNS,   KC.TRNS,   KC.TRNS, KC.TRNS, KC.TRNS,         KC.TRNS, KC.TRNS,   KC.TRNS,   KC.TRNS,    KC.TRNS,\
             KC.TRNS,   KC.TRNS,   KC.TRNS, KC.TRNS, KC.TRNS,         KC.TRNS, KC.TRNS,   KC.TRNS,   KC.TRNS,    KC.TRNS,\
    ],

)


if __name__ == '__main__':
    keyboard.go(hid_type=HIDModes.BLE, ble_name='fulcrum')

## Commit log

2023-01-13 add STLs
    [fulcrum-top-plate.stl, fumcrum-bottom-case.stl, joystick.stl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]
2023-01-13 add correct STLs
    [fulcrum-bottom-case.stl, fulcrum-top-plate.stl, joystick.stl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]
2023-01-13 add joystick mount STLs
    [joystick-mount-bottom.stl, joystick-mount-top.stl]
2023-01-16 small changes to readme firmware and BOM
2023-01-16 update diode info
2023-01-17 fix two missing letters in keymap guide (#2)
    [code.py]
2023-01-17 From Dev - change H-U-K in layouts (#3)
    * Delete fulcrum-layout-all.jpg
    * better layouts image
    * update readme with better layouts image
    * Delete fulcrum-layout-full.jpg
    * better layouts image - correct file
    * change to correct layouts image file
    * change K-H-U in code.py
    * Delete fulcrum-layouts.jpg
    * add new layout file with larger text
    * change reference to new layouts image
    [code.py]
2023-01-18 addkeycap STLs and organize folders
    [fulcrum-bottom-case.stl, fulcrum-top-plate.stl, joystick-mount-bottom.stl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]
2023-01-18 addkeycap key combo layout diagram
    [fulcrum-top-plate.stl]
2023-01-19 add wiring diagram
2023-01-24 new wiring diagram and README changes
2023-01-28 add 40-key version
    [5-way top.stl, 5-way-bottom.stl, Fulcrum-6x3-Bottom.stl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]
2023-02-01 add 5x3 STLs
    [5x3-fulcrum-bottom.stl, 5x3-fulcrum-top.stl]
2023-02-01 update case STLs and add 5x3 beta firmware
    [5x3-fulcrum-bottom-left.stl, 5x3-fulcrum-bottom-right.stl, 5x3-fulcrum-bottom.stl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]
2023-02-09 better layer keymap, updated STLs, and README changes - had to pull first, then stage after renaming
    [5x3-fulcrum-bottom-left.stl, 5x3-fulcrum-bottom-right.stl, 5x3-fulcrum-top-left.stl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]
2023-02-09 re-adding 34-key beta files
    [5x3-fulcrum-bottom-left.stl, 5x3-fulcrum-bottom-right.stl, 5x3-fulcrum-top-left.stl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]
2023-02-13 changed 20-key pinout wiring
2023-02-18 add full wiring diagram and credit for levpopov LPX keycaps
2023-03-04 add beta models for SKRH 5-way-switches
    [SKRH-cover.stl, SKRH-joystick.stl, SKRH-platform.stl]
